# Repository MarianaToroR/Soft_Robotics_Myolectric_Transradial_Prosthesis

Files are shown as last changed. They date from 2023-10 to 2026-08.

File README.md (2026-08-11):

# Soft Robotics Myoelectric Transradial Prosthesis

Open-source repository for the undergraduate thesis **“Soft Robotics Prototype of a Transradial Myoelectric Prosthesis”**, developed by **Mariana Toro Ramírez** and **María Alejandra Mejía Ramírez** as part of the B.Sc. in Mechatronics Engineering at Universidad EIA, under the supervision of Prof. David Rozo Osorio.

## About the Project

This project focused on the design, development, and evaluation of a functional prototype of a transradial myoelectric prosthesis using soft-robotics principles.

The prosthesis integrates mechanical, electronic, signal-processing, and control systems into a single prototype. Its mechanical design uses cable-driven, underactuated mechanisms and flexible structures to reproduce selected movements of the human hand while reducing mechanical and control complexity. The system captures electromyographic (EMG) signals from the user, conditions and digitizes these signals, and processes them through an embedded control system to identify the user's intended action and actuate the prosthetic hand accordingly.

The prototype was designed to perform four common grasp types while incorporating considerations of functionality, ergonomics, robustness, manufacturability, and accessibility. Particular attention was given to the Colombian context and to the potential of rapid-manufacturing and open-source approaches to contribute to the development of more accessible upper-limb prosthetic technologies.

## Repository Contents

This repository contains the files generated throughout the design and development of the prosthesis, including:

- **Mechanical design:** CAD models and files for the socket, palm, fingers, thumb mechanism, and prosthesis assembly.
- **Electronic design:** schematics and PCB design files for the two-channel EMG acquisition and conditioning system, including integration of the MCP3561 analog-to-digital converter and ESP32 microcontroller.
- **PCB manufacturing:** files required for fabrication and assembly of the electronic board, including manufacturing-related documentation.
- **Signal processing and embedded control:** source code for EMG signal acquisition and processing, ADC configuration, grasp classification, and motor control.
- **Simulation files:** electronic simulations used during the design and validation of the EMG signal-conditioning circuitry.

The repository was created as an open-source resource to facilitate the continuation, reproduction, and further development of the project.

## Abstract

This research focuses on the development of a prototype of a transradial myoelectric prosthesis using soft robotics technology for amputated limbs. The relevance of the development focuses on the need to improve the quality of life of the amputated people, highlighting the importance of generating a functional and ergonomic product, mainly framed in the Colombian society and context. The analysis of the current state of the art precedes a detailed description of the adopted methodology. Preliminary research focuses on key aspects such as hand biomechanics and a review of the most recent advances in the field of prosthetics, with emphasis on the use of underactuated transmission and coupled motion architectures. An EMG circuit capable of capturing myoelectric signals, allowing for adaptability to different users and muscles is designed; also, a mechanical design is developed that includes the construction of a socket, palm, and fingers, following the anthropometric characteristics of a mature female user, actuated by cables, which allows performing the movements of abduction and adduction of the thumb, and exion and extension of all fingers, allowing to execute four types of grasps that statistically an average user executes most frequently in their daily activities. A myoelectric control algorithm is developed, which identifies, classifies, and executes the grasps on the user’s demand. Optimization of
the control code and improvements in the mechanical system are suggested for future research. Finally, it is concluded that the project has achieved its objectives in terms of functionality and performance.

**Keywords:** Soft Robotics, Transradial Prosthesis, Myoelectric Signal, EMG.

## Thesis

The complete thesis is available through the Universidad EIA institutional repository:

**Toro Ramírez, M., & Mejía Ramírez, M. A. (2023). _Prototipo en robótica suave de prótesis mioeléctrica transradial_. Universidad EIA.**

https://repository.eia.edu.co/handle/11190/6398

## Authors

**Mariana Toro Ramírez**  
B.Sc. Mechatronics Engineering, Universidad EIA

**María Alejandra Mejía Ramírez**  
B.Sc. Mechatronics Engineering, Universidad EIA

### Thesis Supervisor

**Prof. David Rozo Osorio**  
MEng. Mechatronics, Robotics and Automation Engineering, Universidad Pontificia Bolivariana

WhatsApp Image 2023-10-22 at 08 35 48

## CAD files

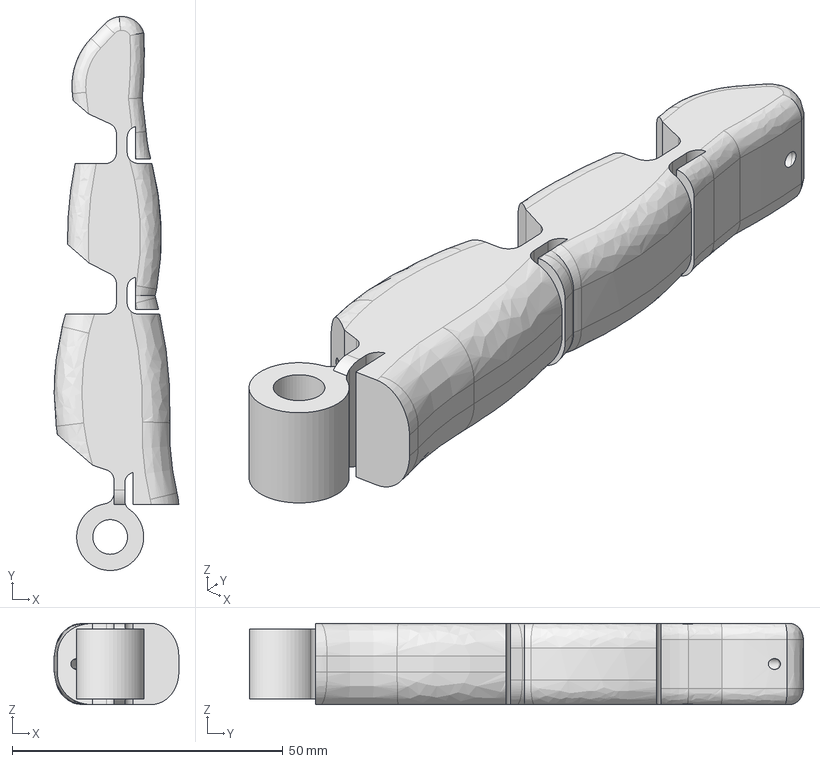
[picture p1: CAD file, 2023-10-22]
CAD_files/Fingers/step/Middle_Design.stp
23.0 x 102.3 x 15.0 mm

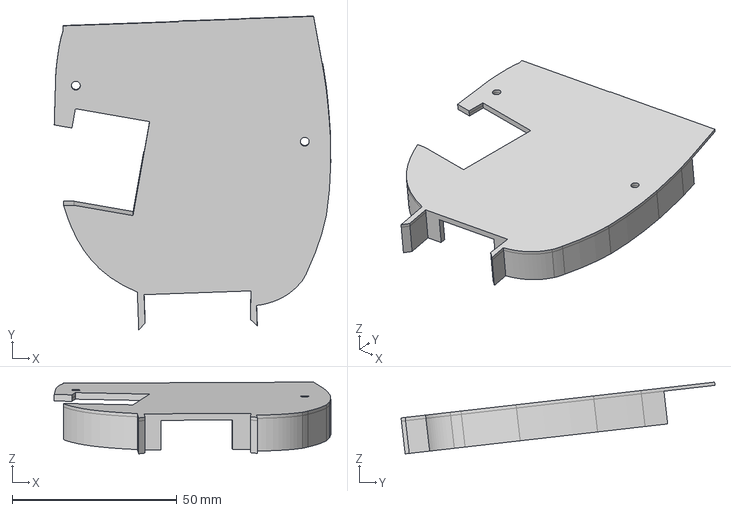
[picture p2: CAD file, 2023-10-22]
CAD_files/Palm/step/palm_cover.step
83.9 x 95.3 x 21.8 mm

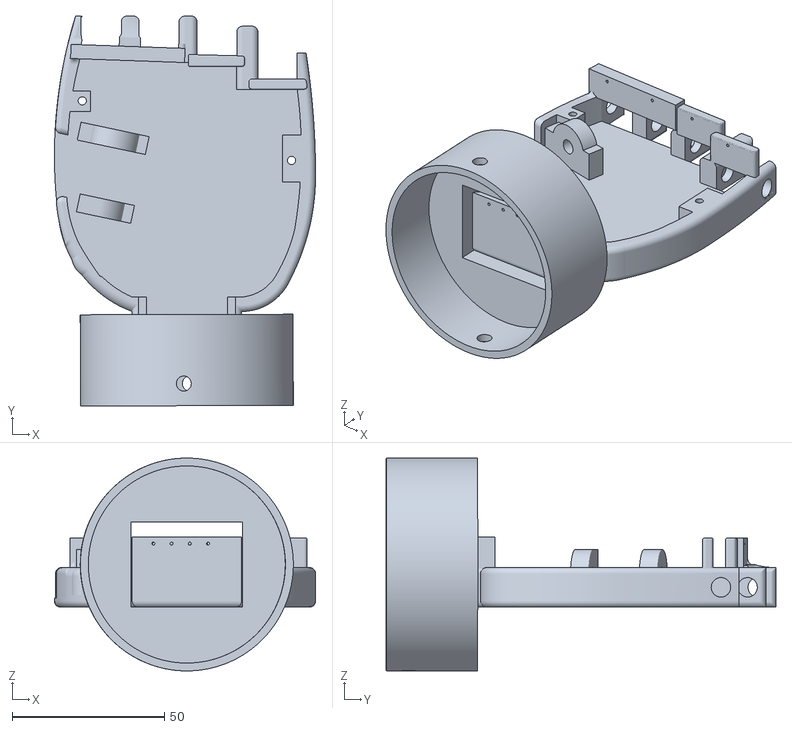
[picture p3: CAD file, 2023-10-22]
CAD_files/Palm/stl/palm_base.stl
85.9 x 128.3 x 70.0

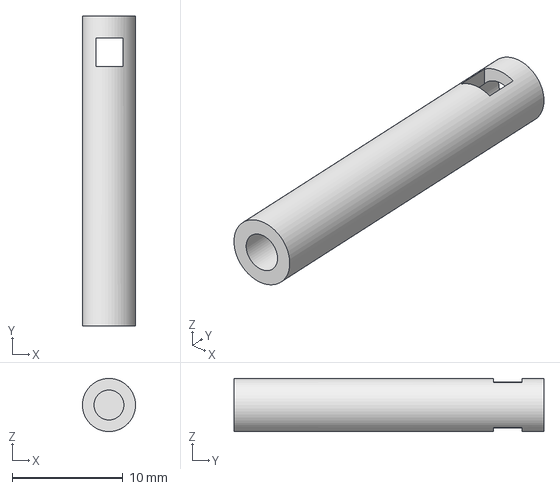
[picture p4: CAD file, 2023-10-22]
CAD_files/Shafts/step/Shaft.stp
4.80 x 28.0 x 4.80 mm

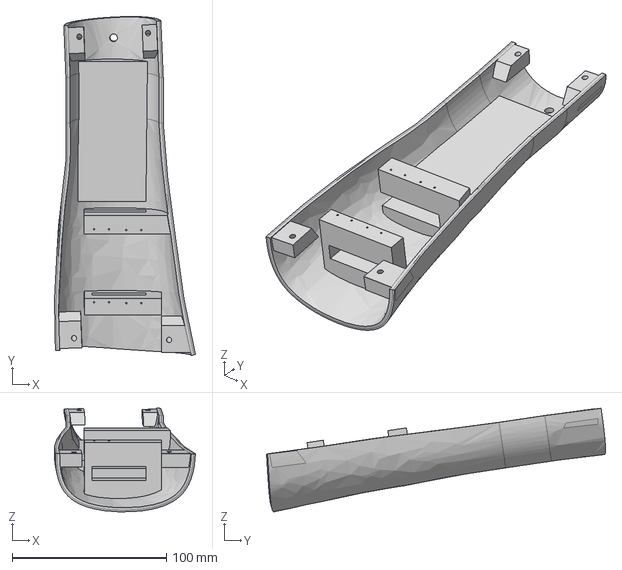
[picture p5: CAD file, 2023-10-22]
CAD_files/Socket/step/Inferior.step
91.6 x 220.1 x 67.3 mm

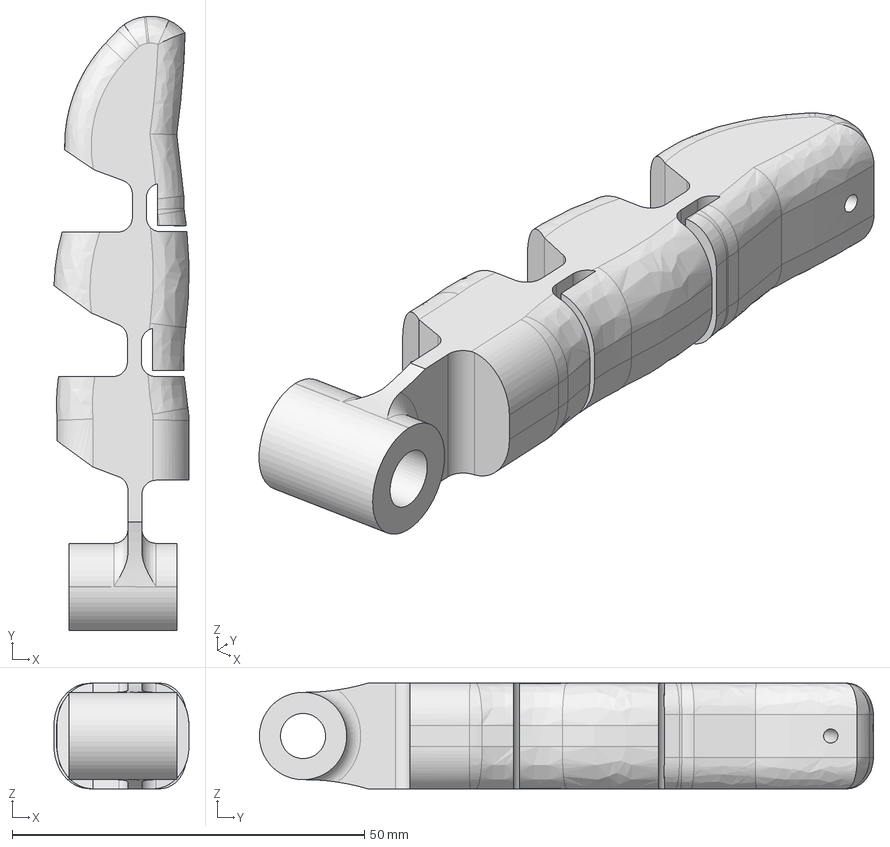
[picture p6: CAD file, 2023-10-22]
CAD_files/Fingers/step/Thumb_Design.stp
19.2 x 87.2 x 15.0 mm

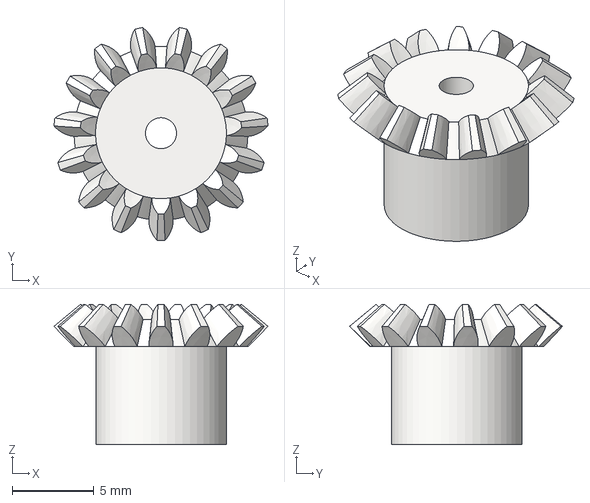
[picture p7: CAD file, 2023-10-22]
CAD_files/Shafts/step/Conic2.stp
13.1 x 13.0 x 8.59 mm

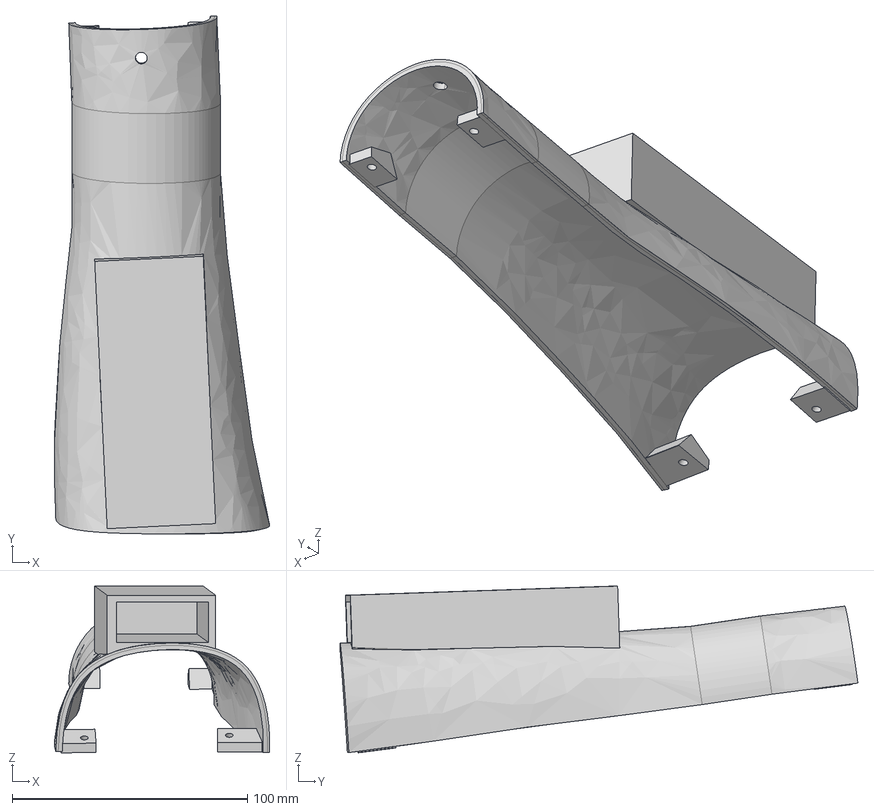
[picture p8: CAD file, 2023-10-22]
CAD_files/Socket/step/Superior.step
91.6 x 220.4 x 71.0 mm

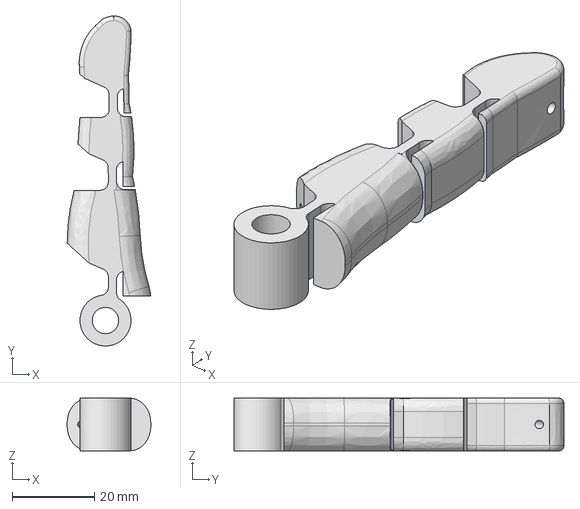
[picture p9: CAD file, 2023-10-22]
CAD_files/Fingers/step/Pinky_Design.stp
20.3 x 80.2 x 12.8 mm

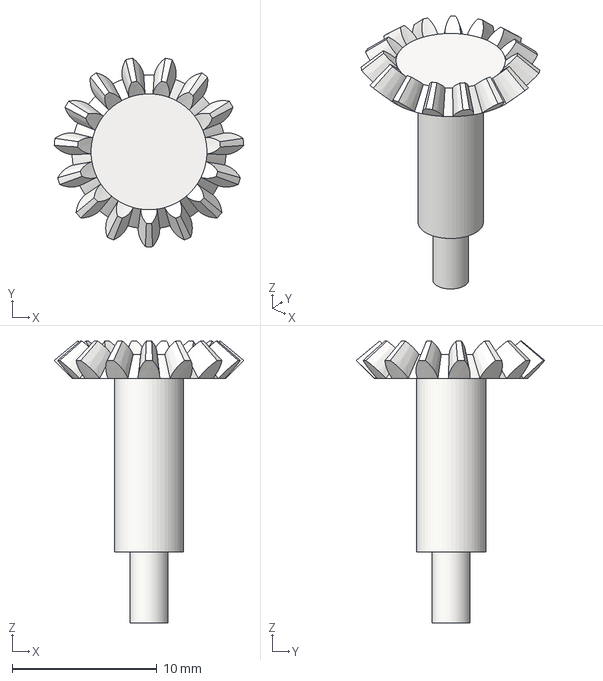
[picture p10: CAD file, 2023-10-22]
CAD_files/Shafts/step/Conic1.stp
13.1 x 13.0 x 19.5 mm

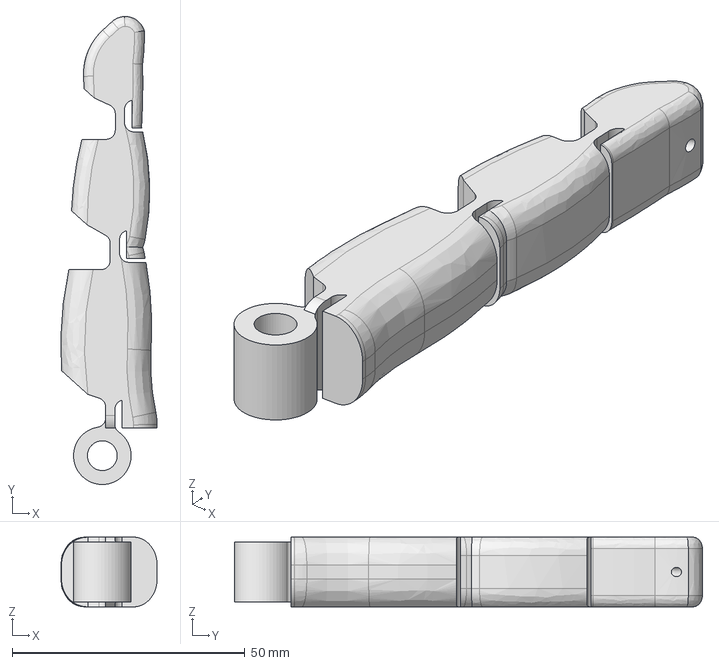
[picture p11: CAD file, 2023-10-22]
CAD_files/Fingers/step/Ring_Design.stp
20.7 x 100.6 x 15.0 mm

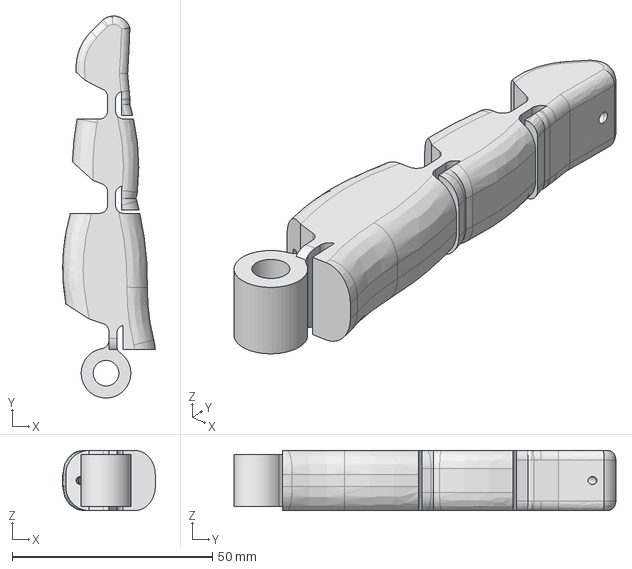
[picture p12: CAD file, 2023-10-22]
CAD_files/Fingers/step/Index_Design.stp
23.1 x 95.4 x 15.0 mm

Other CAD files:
CAD_files/Fingers/stl/Index_Design.stl
CAD_files/Fingers/stl/Middle_Design.stl
CAD_files/Fingers/stl/Pinky_Design.stl
CAD_files/Fingers/stl/Ring_Design.stl
CAD_files/Fingers/stl/Thumb_Design.stl
CAD_files/Palm/stl/palm_cover.stl
CAD_files/Shafts/stl/Conic1.stl
CAD_files/Shafts/stl/Conic2.stl
CAD_files/Shafts/stl/Shaft.stl
CAD_files/Socket/stl/Inferior.stl
CAD_files/Socket/stl/Superior.stl

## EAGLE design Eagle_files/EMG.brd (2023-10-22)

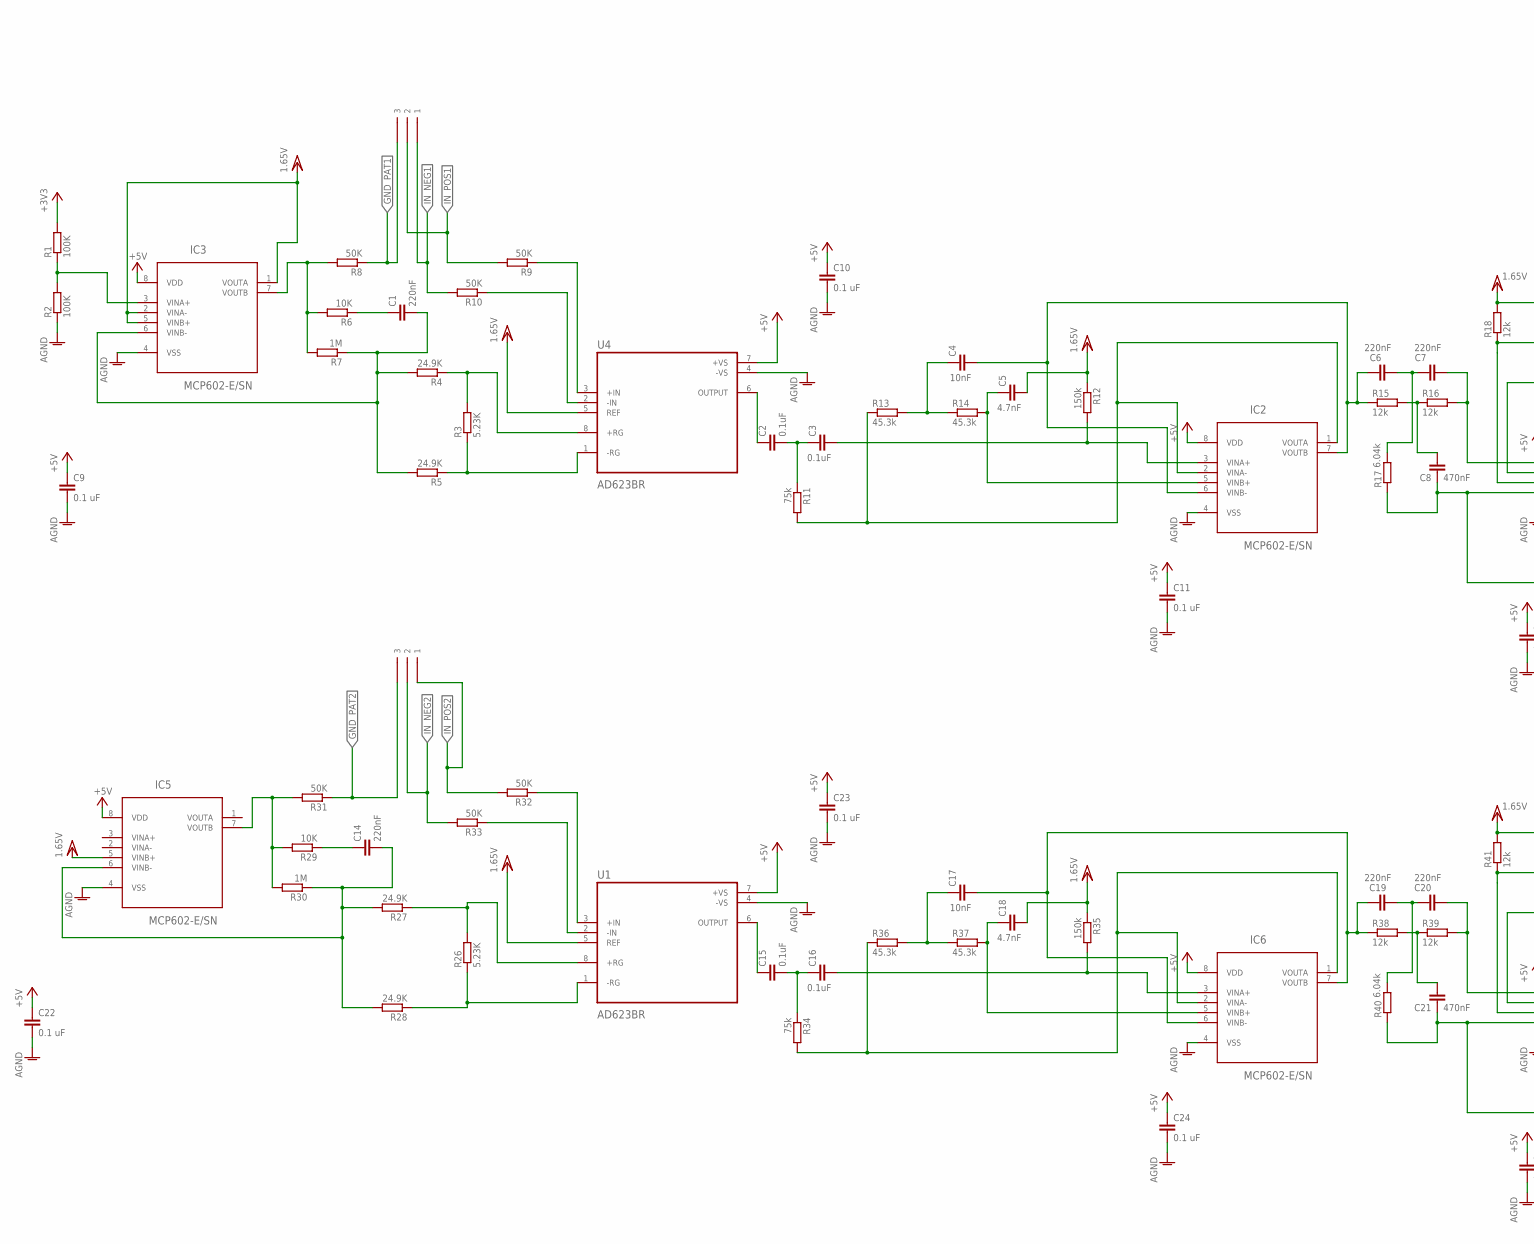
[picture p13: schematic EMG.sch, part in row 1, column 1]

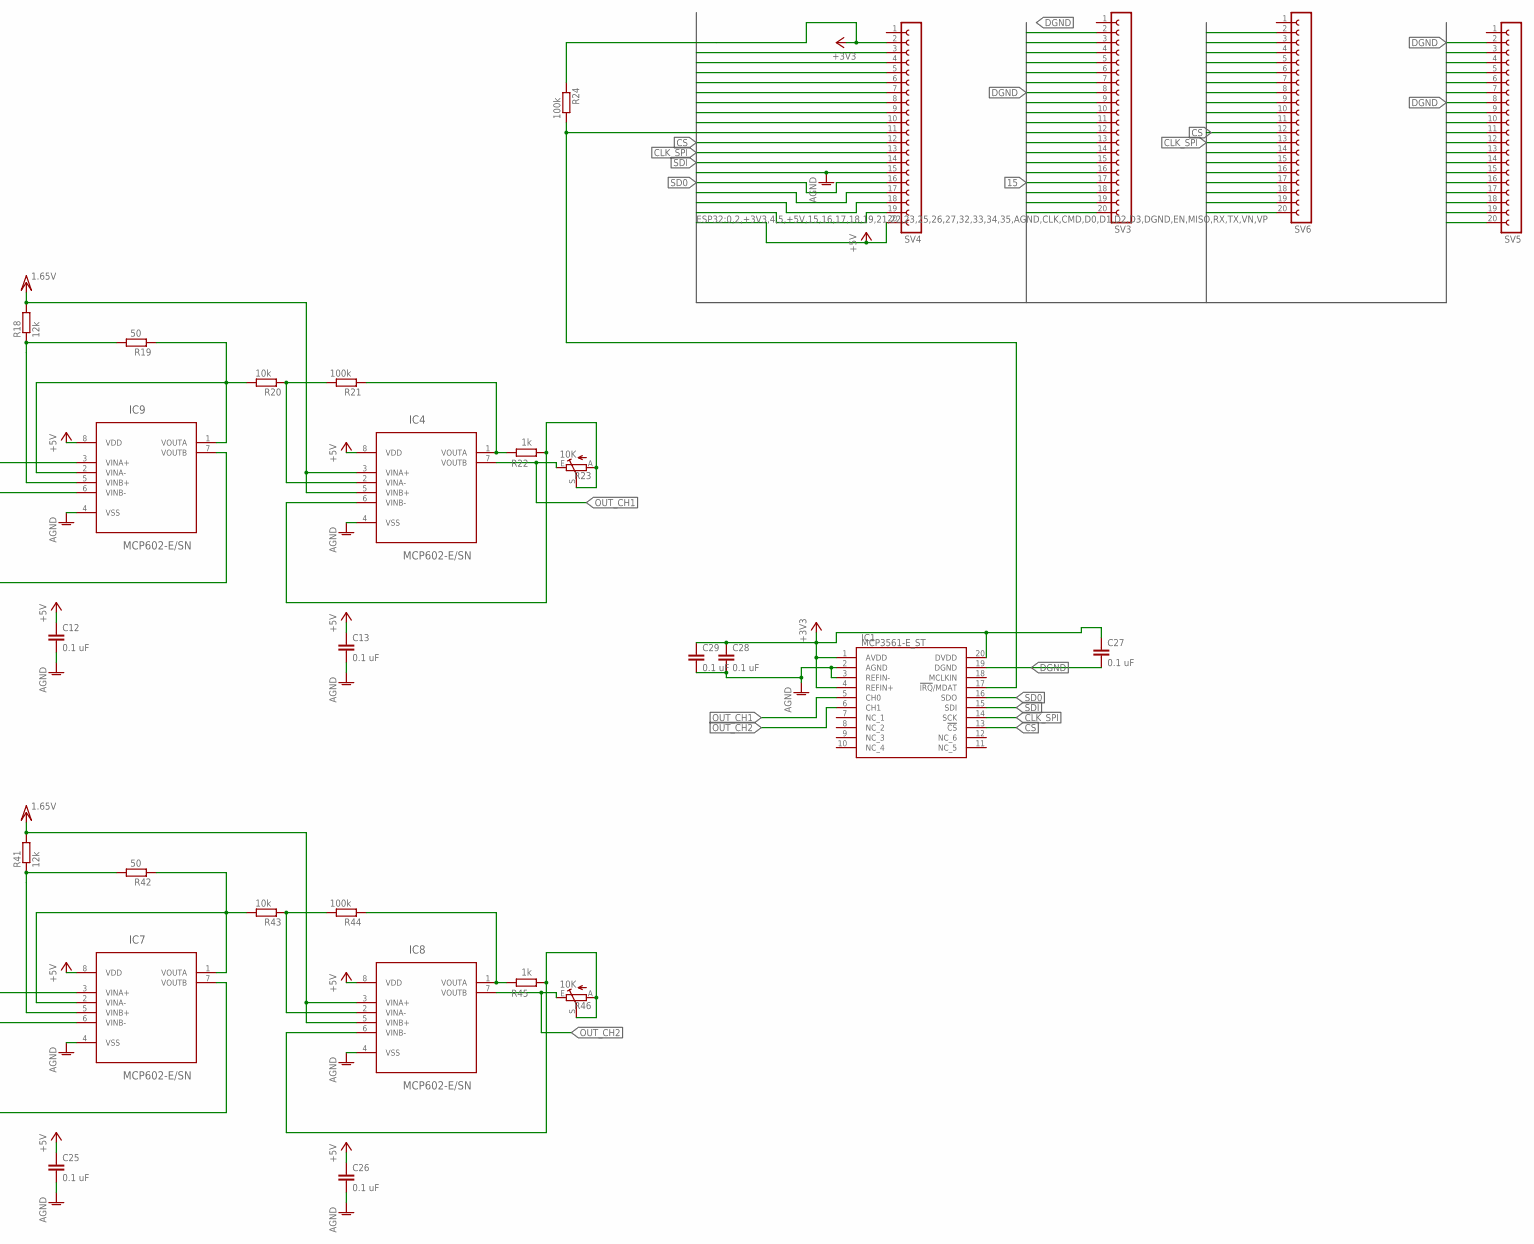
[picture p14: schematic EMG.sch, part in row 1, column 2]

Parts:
C1, C6, C7, C14, C19, C20: 220nF; C0402
C2, C3, C15, C16: 0.1uF; C0402
C4, C17: 10nF; C0402
C5, C18: 4.7nF; C0402
C8, C21: 470nF; C0402
C9, C10, C11, C12, C13, C22, C23, C24, C25, C26, C27, C28, C29: 0.1 uF; C0402
CON1, CON2: PW3; PWR3
IC1: MCP3561-E_ST; SOP65P640X120-20N
IC2, IC3, IC4, IC5, IC6, IC7, IC8, IC9: MCP602-E/SN; SOIC127P600X175-8N
R1, R2: 100K; R0402
R3, R26: 5.23K; R0402
R4, R5, R27, R28: 24.9K; R0402
R6, R29: 10K; R0402
R7, R30: 1M; R0402
R8, R9, R10, R31, R32, R33: 50K; R0402
R11, R34: 75k; R0402
R12, R35: 150k; R0402
R13, R14, R36, R37: 45.3k; R0402
R15, R16, R18, R38, R39, R41: 12k; R0402
R17, R40: 6.04k; R0402
R19, R42: 50; R0402
R20, R43: 10k; R0402
R21, R24, R44: 100k; R0402
R22, R45: 1k; R0402
R23, R46: 10K; CA6V
SV3, SV4, SV5, SV6: FE20-1; FE20
U1, U4: AD623BR; SOIC127P600X175-8N

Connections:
0: SV3.15, SV5.15
2: SV3.16, SV5.16
4: SV3.14, SV5.14
5: SV3.11, SV5.11
15: SV3.17, SV5.17
16: SV3.13, SV5.13
17: SV3.12, SV5.12
18: SV3.10, SV5.10
19: SV3.9, SV5.9
21: SV3.7, SV5.7
22: SV3.4, SV5.4
23: SV3.3, SV5.3
25: SV4.10, SV6.10
26: IC1.17 (!IRQ!/MDAT), R24.2, SV4.11, SV6.11
32: SV4.8, SV6.8
33: SV4.9, SV6.9
34: SV4.6, SV6.6
35: SV4.7, SV6.7
+3V3: C27.1, C28.1, C29.1, IC1.1 (AVDD), IC1.4 (REFIN+), IC1.20 (DVDD), R1.2, R24.1, SV4.2, SV6.2
+5V: C9.1, C10.1, C11.1, C12.1, C13.1, C22.1, C23.1, C24.1, C25.1, C26.1, IC2.8 (VDD), IC3.8 (VDD), IC4.8 (VDD), IC5.8 (VDD), IC6.8 (VDD), IC7.8 (VDD), IC8.8 (VDD), IC9.8 (VDD), SV4.20, SV6.20, U1.7 (+VS), U4.7 (+VS)
AGND: C9.2, C10.2, C11.2, C12.2, C13.2, C22.2, C23.2, C24.2, C25.2, C26.2, C28.2, C29.2, IC1.2 (AGND), IC1.3 (REFIN-), IC2.4 (VSS), IC3.4 (VSS), IC4.4 (VSS), IC5.4 (VSS), IC6.4 (VSS), IC7.4 (VSS), IC8.4 (VSS), IC9.4 (VSS), R2.1, SV4.15, SV6.15, U1.4 (-VS), U4.4 (-VS)
CLK: SV3.20, SV5.20
CLK_SPI: IC1.14 (SCK), SV4.13, SV6.13
CMD: SV4.19, SV6.19
CS: IC1.13 (!CS), SV4.12, SV6.12
D0: SV3.19, SV5.19
D1: SV3.18, SV5.18
D2: SV4.17, SV6.17
D3: SV4.18, SV6.18
DGND: C27.2, IC1.19 (DGND), SV3.2, SV3.8, SV5.2, SV5.8
EN: SV4.3, SV6.3
GND_PAT1: CON2.P$3 (3), R8.1
GND_PAT2: CON1.P$3 (3), R31.1
IN_NEG1: CON2.P$1 (1), R10.2
IN_NEG2: CON1.P$2 (2), R33.2
IN_POS1: CON2.P$2 (2), R9.2
IN_POS2: CON1.P$1 (1), R32.2
unnamed: IC3.3 (VINA+), R1.1, R2.2
unnamed: C1.2, IC3.6 (VINB-), R4.2, R5.2, R7.1
unnamed: R3.1, R5.1, U4.1 (-RG)
unnamed: R3.2, R4.1, U4.8 (+RG)
unnamed: C2.1, U4.6 (OUTPUT)
unnamed: C1.1, R6.1
unnamed: R9.1, U4.3 (+IN)
unnamed: R10.1, U4.2 (-IN)
unnamed: C2.2, C3.1, R11.1
unnamed: IC2.1 (VOUTA), IC2.2 (VINA-), R11.2, R13.1
unnamed: C3.2, IC2.3 (VINA+), R12.2
unnamed: C4.1, R13.2, R14.1
unnamed: IC9.1 (VOUTA), IC9.2 (VINA-), R19.1, R20.2
unnamed: C5.1, IC2.5 (VINB+), R14.2
unnamed: C6.2, C7.1, R17.2
unnamed: C8.2, R15.2, R16.1
unnamed: C4.2, C6.1, IC2.6 (VINB-), IC2.7 (VOUTB), R15.1
unnamed: C7.2, IC9.3 (VINA+), R16.2
unnamed: IC9.5 (VINB+), R18.1, R19.2
unnamed: IC4.2 (VINA-), R20.1, R21.2
unnamed: C8.1, IC9.6 (VINB-), IC9.7 (VOUTB), R17.1
unnamed: IC4.1 (VOUTA), R21.1, R22.1
unnamed: IC4.6 (VINB-), R22.2, R23.A, R23.S
unnamed: C14.2, IC5.6 (VINB-), R27.2, R28.2, R30.1
unnamed: R26.1, R28.1, U1.1 (-RG)
unnamed: R26.2, R27.1, U1.8 (+RG)
unnamed: C14.1, R29.1
unnamed: R32.1, U1.3 (+IN)
unnamed: R33.1, U1.2 (-IN)
unnamed: C15.1, U1.6 (OUTPUT)
unnamed: C15.2, C16.1, R34.1
unnamed: IC6.1 (VOUTA), IC6.2 (VINA-), R34.2, R36.1
unnamed: C16.2, IC6.3 (VINA+), R35.2
unnamed: C17.1, R36.2, R37.1
unnamed: C18.1, IC6.5 (VINB+), R37.2
unnamed: C19.2, C20.1, R40.2
unnamed: C21.2, R38.2, R39.1
unnamed: C17.2, C19.1, IC6.6 (VINB-), IC6.7 (VOUTB), R38.1
unnamed: C20.2, IC7.3 (VINA+), R39.2
unnamed: IC7.1 (VOUTA), IC7.2 (VINA-), R42.1, R43.2
unnamed: C21.1, IC7.6 (VINB-), IC7.7 (VOUTB), R40.1
unnamed: IC7.5 (VINB+), R41.1, R42.2
unnamed: IC8.2 (VINA-), R43.1, R44.2
unnamed: IC8.1 (VOUTA), R44.1, R45.1
unnamed: IC8.6 (VINB-), R45.2, R46.A, R46.S
OUT_CH1: IC1.5 (CH0), IC4.7 (VOUTB), R23.E
OUT_CH2: IC1.6 (CH1), IC8.7 (VOUTB), R46.E
OUT_REF: IC3.7 (VOUTB), R6.2, R7.2, R8.2
OUT_REF1: IC5.7 (VOUTB), R29.2, R30.2, R31.2
RX: SV3.6, SV5.6
SD0: IC1.16 (SDO), SV4.16, SV6.16
SDI: IC1.15 (SDI), SV4.14, SV6.14
TX: SV3.5, SV5.5
VCC/2: C5.2, C18.2, IC3.1 (VOUTA), IC3.2 (VINA-), IC3.5 (VINB+), IC4.3 (VINA+), IC4.5 (VINB+), IC5.5 (VINB+), IC8.3 (VINA+), IC8.5 (VINB+), R12.1, R18.2, R35.1, R41.2, U1.5 (REF), U4.5 (REF)
VN: SV4.5, SV6.5
VP: SV4.4, SV6.4

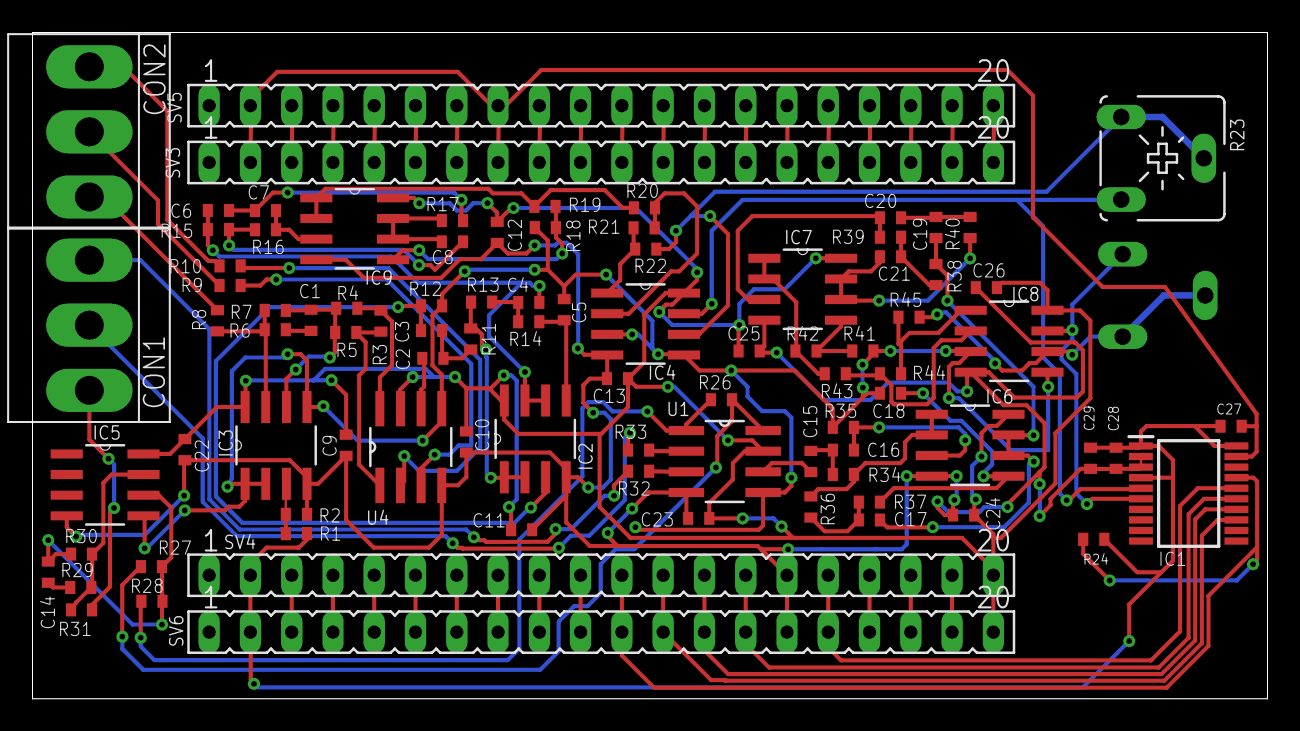
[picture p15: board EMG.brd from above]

Board: 2 copper layers, 76.0 x 41.0 mm, 91 parts (1 on the bottom side), 93 nets.

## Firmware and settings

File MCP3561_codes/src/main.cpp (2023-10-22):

#include "ADC_read.h"

uint8_t ChannelID;
double ADCConversion;
ADCReader ADC;

//const int IRQ = 26;
//uint8_t newData=0;

// void IRQ_data() {
//   newData=1;
// }

void setup() { //Corre una sola vez
  ADC.begin();
  ADC.configureRegisters();
  delay(50);
  //pinMode(IRQ, INPUT);
  //attachInterrupt(digitalPinToInterrupt(IRQ), IRQ_data, FALLING); // Configura la interrupción en el flanco de bajada
  //ADC.lockConfig();
  //ADC.unlockConfig();
}

void loop() {
  
  //ADC.readADC(ChannelID, ADCConversion);
  //Serial.print("ChannelID: ");
  //Serial.println(ChannelID);
  //Serial.print("ADCConversion: ");
  //Serial.println(ADCConversion);
  //delay(1);
  
}

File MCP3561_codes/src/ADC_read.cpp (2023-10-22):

#include "ADC_read.h"

ADCReader::ADCReader() {

}

void ADCReader::begin() {
  // Inicializa el bus SPI personalizado
  SPI.begin(SCK, MISO, MOSI);

  // 25 kHz, MSB primero, Modo 1
  SPI.beginTransaction(SPISettings(25000, MSBFIRST, SPI_MODE0));
  
  Serial.begin(9600);
  
  pinMode (CS, OUTPUT);
  digitalWrite(CS, HIGH); // Deseleccionar el MCP3561 inicialmente
}

void ADCReader::configureRegisters() {
  //Configuraciones de registros:
  config0=0x23; //reg add: 0x1 //reg. value: 0010 0011
  config1=0x0C; //reg add: 0x2 //reg. value: 0000 1100
  config2=0x8B; //reg add: 0x3 //reg. value: 1000 1011
  config3=0xF0; //reg add: 0x4 //reg. value: 1111 0000
  IRQ=0x00; //reg add: 0x5 //reg. value: 0000 0000
  SCAN1=0xC0; //reg add: 0x7
  SCAN2=0x00;
  //SCAN3=0x02; //Lea solo canal 1
  SCAN3=0x01; //Lea solo canal 0
  //SCAN3=0x03; //Lea ambos canales
  TIMER1=0x00; //reg. add: 0x8
  TIMER2=0x00;
  TIMER3=0x80;
  //Se configuran los registros congig0-IRQ
  digitalWrite(CS, LOW);
  buffer_w[0] = 0x46;     // Asigna 0x46 al primer elemento del arreglo
  buffer_w[1] = config0; // Asigna el valor de config0 al segundo elemento del arreglo
  buffer_w[2] = config1; // Asigna el valor de config1 al tercer elemento del arreglo
  buffer_w[3] = config2; // Asigna el valor de config2 al cuarto elemento del arreglo
  buffer_w[4] = config3; // Asigna el valor de config3 al quinto elemento del arreglo
  buffer_w[5] = IRQ;
  Serial.print("Instruction Write: ");
  for (int i = 0; i < sizeof(buffer_w); i++) {
    Serial.print(buffer_w[i], HEX);
  }
  Serial.println("");
  SPI.transfer(&buffer_w, 6); //Se mandan 6 bytes de datos
  digitalWrite(CS, HIGH);
  Serial.print("Write answer: ");
  for (int i = 0; i < sizeof(buffer_w); i++) {
    Serial.print(buffer_w[i], HEX);
  }
  Serial.println("");

  delay(10);

  //Se leen los registros config0-IRQ que se acaban de configurar
  digitalWrite(CS, LOW);
  buffer_r[0] = 0x47;     // Asigna 0x47 al primer elemento del arreglo
  buffer_r[1] = 0;
  buffer_r[2] = 0;
  buffer_r[3] = 0;
  buffer_r[4] = 0;
  buffer_r[5] = 0;
  buffer_r[6] = 0;
  Serial.print("Instruction Read: ");
  for (int i = 0; i < sizeof(buffer_r); i++) {
    Serial.print(buffer_r[i], HEX);
  }
  Serial.println("");
  SPI.transfer(&buffer_r, 6); //Se leen 6 bytes de datos
  digitalWrite(CS, HIGH);
  Serial.print("Read answer: ");
  for (int i = 0; i < sizeof(buffer_r); i++) {
    Serial.print(buffer_r[i], HEX);
  }
  Serial.println("");

  delay(10);

  //Se configuran los registros SCAN1-TIMER3 
  digitalWrite(CS, LOW);
  buffer_w[0] = 0b01011110;
  buffer_w[1] = SCAN1;
  buffer_w[2] = SCAN2;
  buffer_w[3] = SCAN3;
  buffer_w[4] = TIMER1;
  buffer_w[5] = TIMER2;
  buffer_w[6] = TIMER3;
  Serial.print("Instruction Write: ");
  for (int i = 0; i < sizeof(buffer_w); i++) {
    Serial.print(buffer_w[i], HEX);
  }
  Serial.println("");
  SPI.transfer(&buffer_w, 7); //Se escriben 7 bytes de datos
  digitalWrite(CS, HIGH);
  Serial.print("Write answer: ");
  for (int i = 0; i < sizeof(buffer_w); i++) {
    Serial.print(buffer_w[i], HEX);
  }
  Serial.println("");

  delay(10);

  //Se leen los registros SCAN1-TIMER3 que se acaban de configurar
  digitalWrite(CS, LOW);
  buffer_r[0] = 0x5F;
  buffer_r[1] = 0;
  buffer_r[2] = 0;
  buffer_r[3] = 0;
  buffer_r[4] = 0;
  buffer_r[5] = 0;
  buffer_r[6] = 0;
  Serial.print("Instruction Read: ");
  for (int i = 0; i < sizeof(buffer_r); i++) {
    Serial.print(buffer_r[i], HEX);
  }
  Serial.println("");
  SPI.transfer(&buffer_r, 7); //Se leen 7 bytes de datos
  digitalWrite(CS, HIGH);
  Serial.print("Read answer: ");
  for (int i = 0; i < sizeof(buffer_r); i++) {
    Serial.print(buffer_r[i], HEX);
  }
  Serial.println("");
  //Esta lectura no la hace bien, pero cuando se miran los bits de datos de transmisión, sí se lee correctamente el registro
  
  delay(5000);

}

void ADCReader::lockConfig(){
  //Se lee el registro, deberá ser 0xA5 si se desea desbloquear los registros de configuración
  digitalWrite(CS, LOW);
  buffer_r[0] = 0x75;
  buffer_r[1] = 0;
  Serial.print("Instruction Read: ");
  for (int i = 0; i < sizeof(buffer_r); i++) {
    Serial.print(buffer_r[i], HEX);
  }
  Serial.println("");
  SPI.transfer(&buffer_r, 2); //Se leen 2 bytes de datos
  digitalWrite(CS, HIGH);
  Serial.print("Read answer: ");
  for (int i = 0; i < sizeof(buffer_r); i++) {
    Serial.print(buffer_r[i], HEX);
  }
  Serial.println("");

  delay(10);

  //Se escribe en 0x00
  digitalWrite(CS, LOW);
  buffer_w[0] = 0x76;
  buffer_w[1] = 0;
  Serial.print("Instruction Write: ");
  for (int i = 0; i < sizeof(buffer_w); i++) {
    Serial.print(buffer_w[i], HEX);
  }
  Serial.println("");
  SPI.transfer(&buffer_w, 2); //Se escriben 2 bytes de datos
  digitalWrite(CS, HIGH);
  Serial.print("Write answer: ");
  for (int i = 0; i < sizeof(buffer_w); i++) {
    Serial.print(buffer_w[i], HEX);
  }
  Serial.println("");

  delay(10);

  //Se lee el registro como quedó configurado
  digitalWrite(CS, LOW);
  buffer_r[0] = 0x75;
  buffer_r[1] = 0;
  Serial.print("Instruction Read: ");
  for (int i = 0; i < sizeof(buffer_r); i++) {
    Serial.print(buffer_r[i], HEX);
  }
  Serial.println("");
  SPI.transfer(&buffer_r, 2); //Se leen 2 bytes de datos
  digitalWrite(CS, HIGH);
  Serial.print("Read answer: ");
  for (int i = 0; i < sizeof(buffer_r); i++) {
    Serial.print(buffer_r[i], HEX);
  }
  Serial.println("");

  delay(5000);
}

void ADCReader::unlockConfig(){
  //Se escribe en 0xA5
  digitalWrite(CS, LOW);
  buffer_w[0] = 0x76;
  buffer_w[1] = 0xA5;
  Serial.print("Instruction Write: ");
  for (int i = 0; i < sizeof(buffer_w); i++) {
    Serial.print(buffer_w[i], HEX);
  }
  Serial.println("");
  SPI.transfer(&buffer_w, 2); //Se escriben 2 bytes de datos
  digitalWrite(CS, HIGH);
  Serial.print("Write answer: ");
  for (int i = 0; i < sizeof(buffer_w); i++) {
    Serial.print(buffer_w[i], HEX);
  }
  Serial.println("");

  delay(10);

  //Se lee el registro como quedó configurado
  digitalWrite(CS, LOW);
  buffer_r[0] = 0x75;
  buffer_r[1] = 0;
  Serial.print("Instruction Read: ");
  for (int i = 0; i < sizeof(buffer_r); i++) {
    Serial.print(buffer_r[i], HEX);
  }
  Serial.println("");
  SPI.transfer(&buffer_r, 2); //Se leen 2 bytes de datos
  digitalWrite(CS, HIGH);
  Serial.print("Read answer: ");
  for (int i = 0; i < sizeof(buffer_r); i++) {
    Serial.print(buffer_r[i], HEX);
  }
  Serial.println("");

  delay(1000);
}
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
